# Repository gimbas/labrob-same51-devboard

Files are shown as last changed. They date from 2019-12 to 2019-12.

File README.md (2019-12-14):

# SAME51-DevBoard

small and simple development board for the same51 mcus

## Built With

* eagle cad

## Contributing

Currently not looking for external contributers.

Please read [CONTRIBUTING.md](//) for details on our code of conduct, and the process for submitting pull requests to us.

## Authors

* **Rafael Silva** - *initial work* - [gimbas](https://github.com/gimbas)

See also the list of [contributors](https://github.com/gimbas/labrob-same51-devboard/graphs/contributors) who participated in this project.

## License

This project is licensed under the CC 3.0 License - see the [LICENSE.md](LICENSE.md) file for details

## Acknowledgments

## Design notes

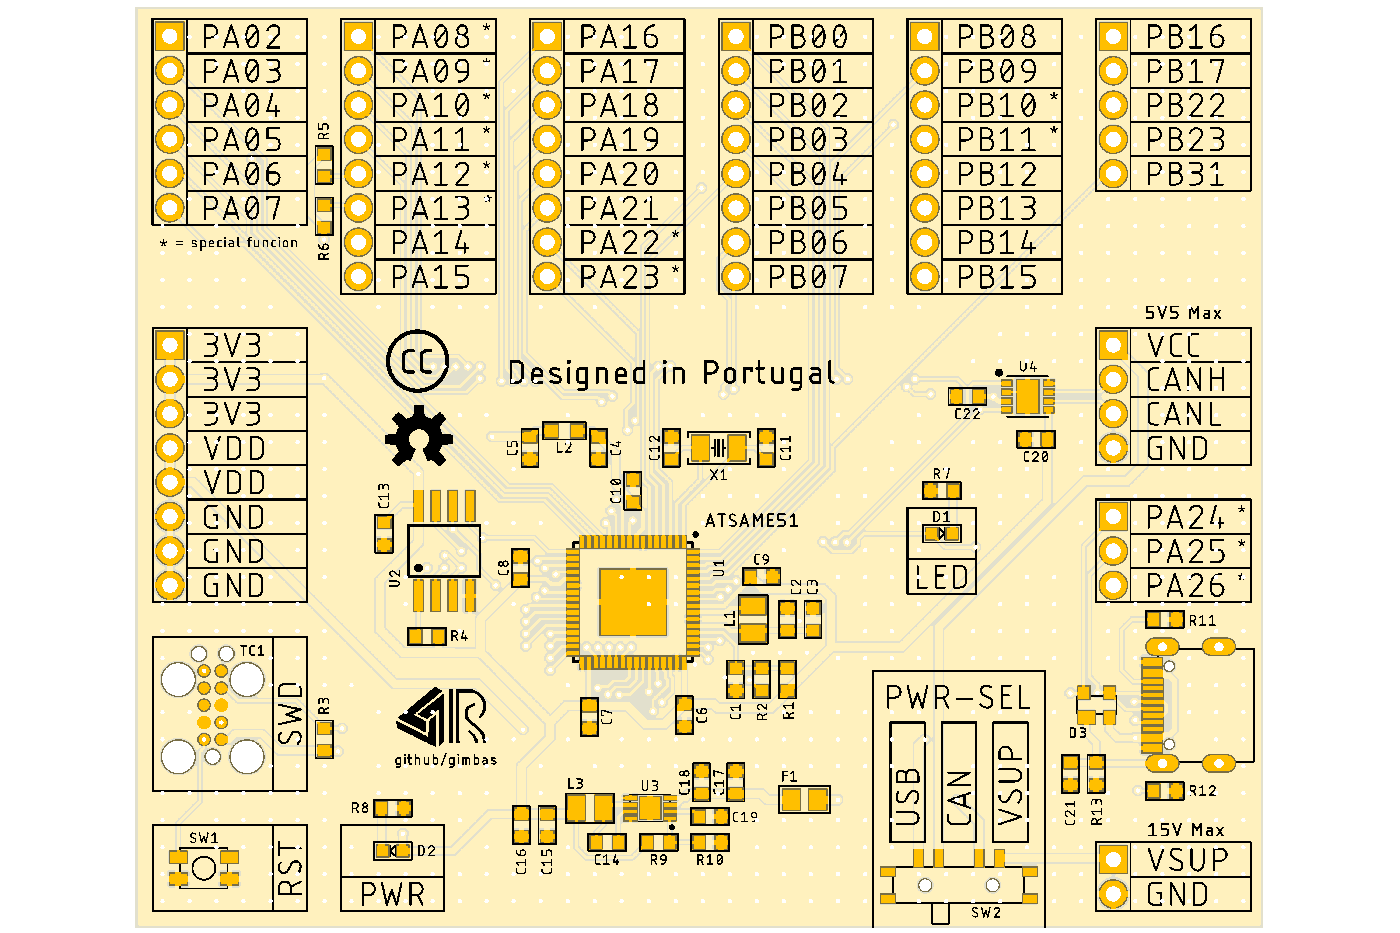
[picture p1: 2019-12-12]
pcb/same51-dev-top-render.png

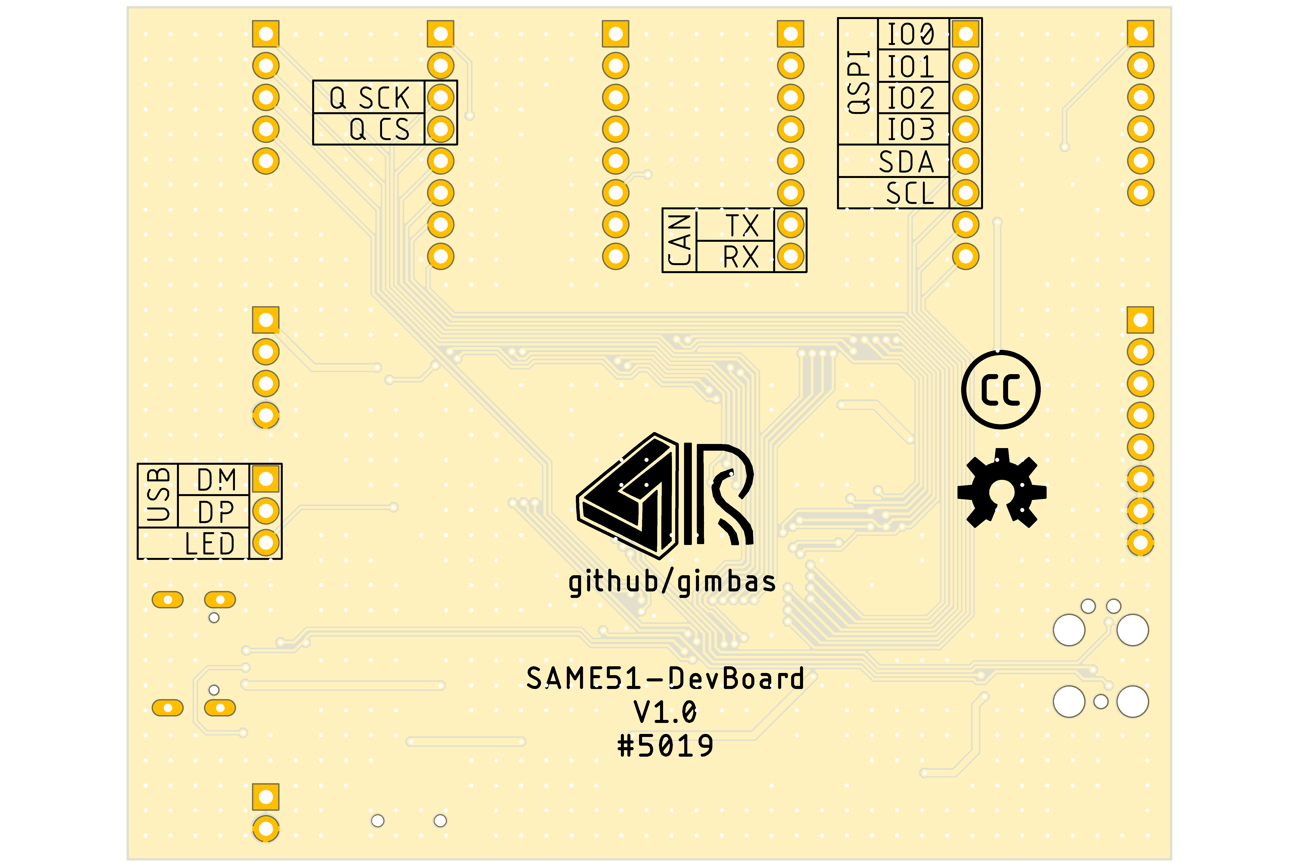
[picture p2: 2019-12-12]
pcb/same51-dev-bot-render.png

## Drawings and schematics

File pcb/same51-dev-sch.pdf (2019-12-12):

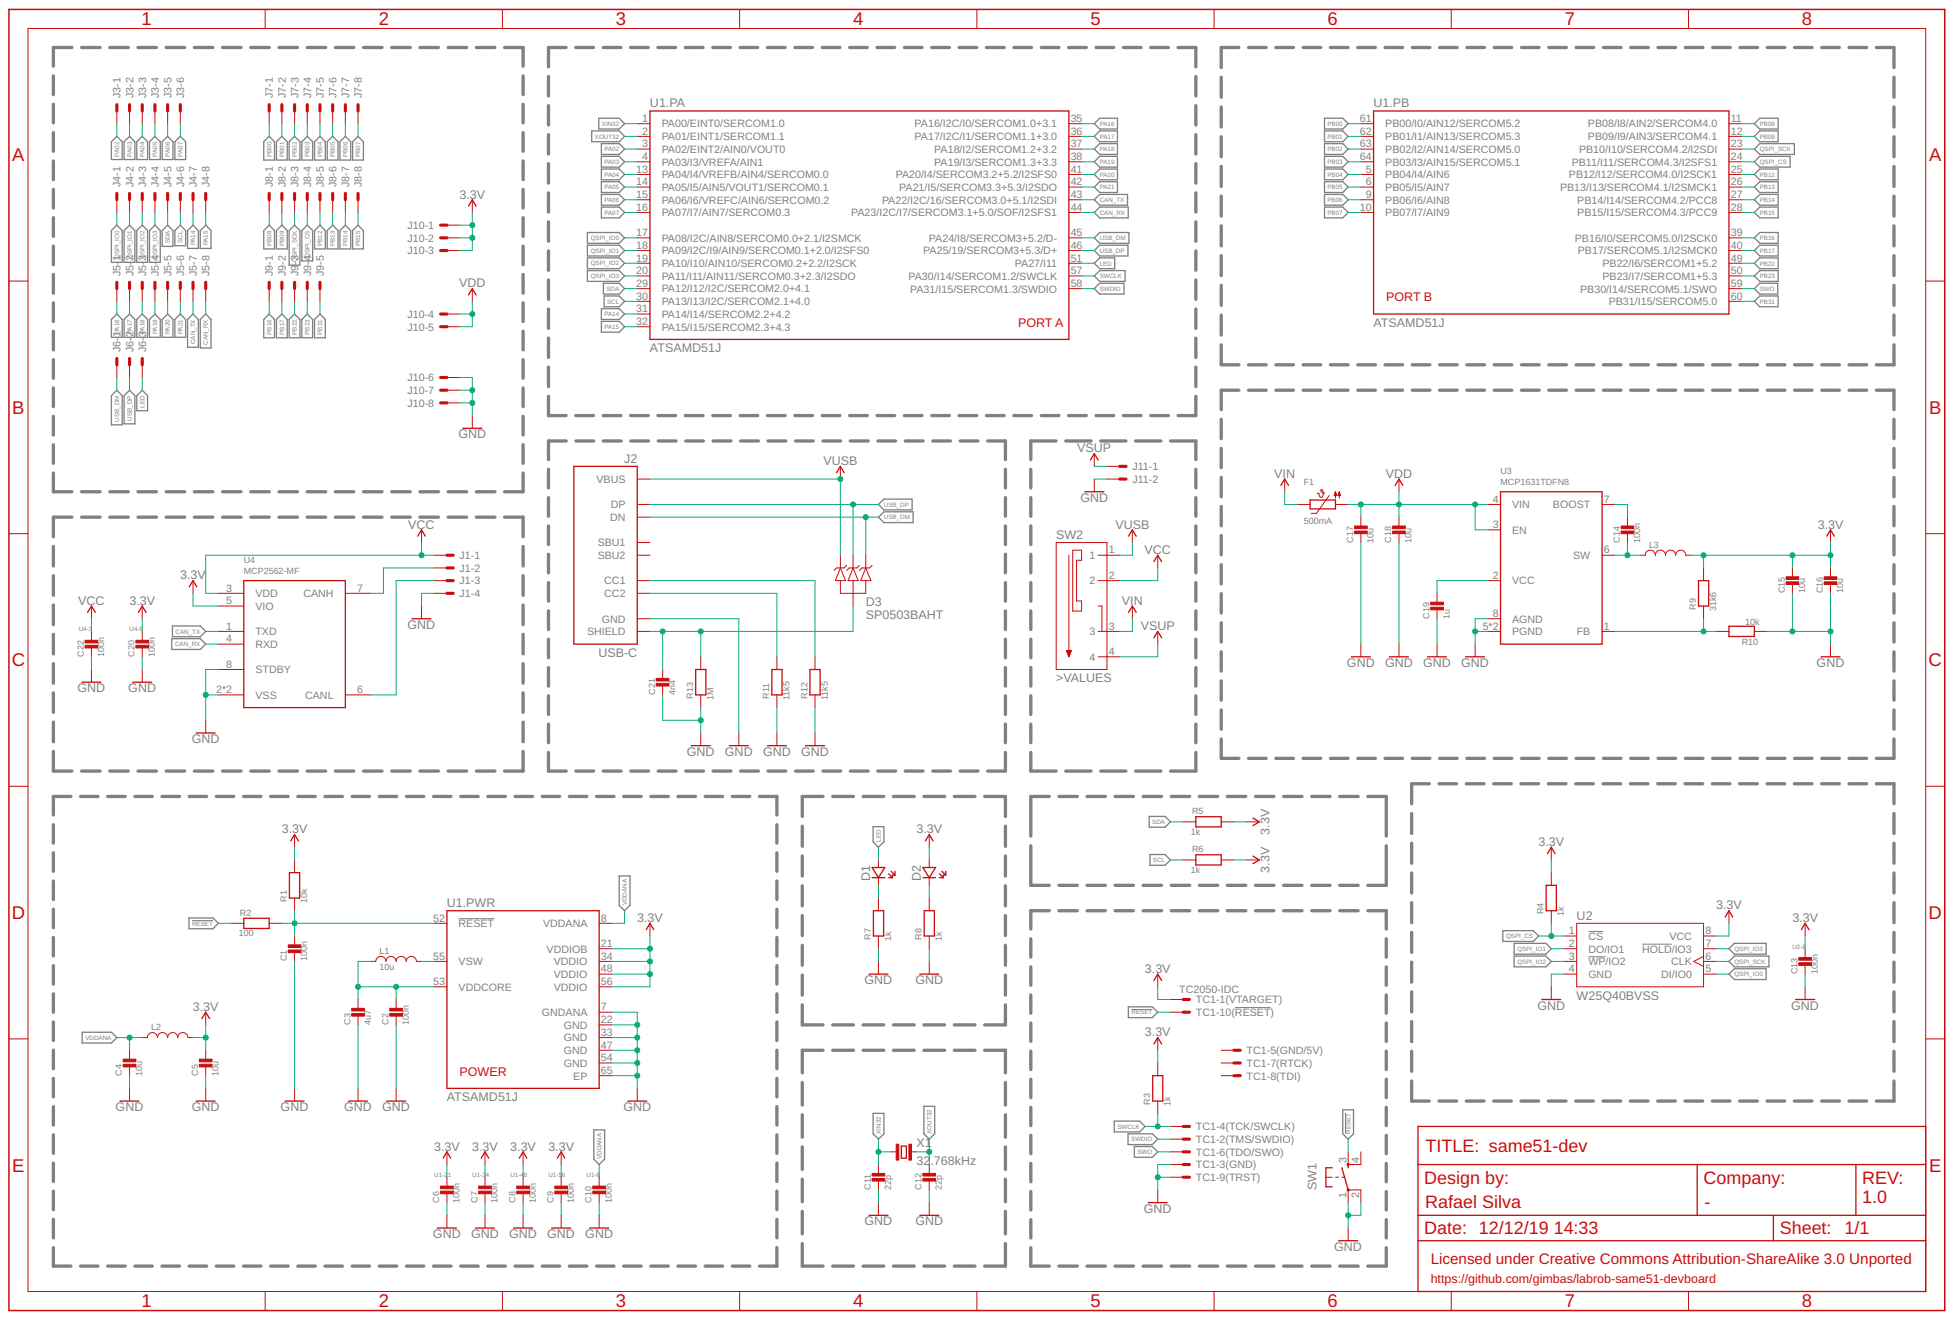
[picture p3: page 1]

n4 GND GND GND GND

TC1-2(TMS/SWDIO) TC1-3(GND) TC1-4(TCK/SWCLK)

Design by: Rafael Silva | Company: - | REV: 1.0

Date: 12/12/19 14:33 | Sheet: 1/1

GND GND GND GND GND

Licensed under Creative Commons Attribution-ShareAlike 3.0 Unported
https://github.com/gimbas/labrob-same51-devboard

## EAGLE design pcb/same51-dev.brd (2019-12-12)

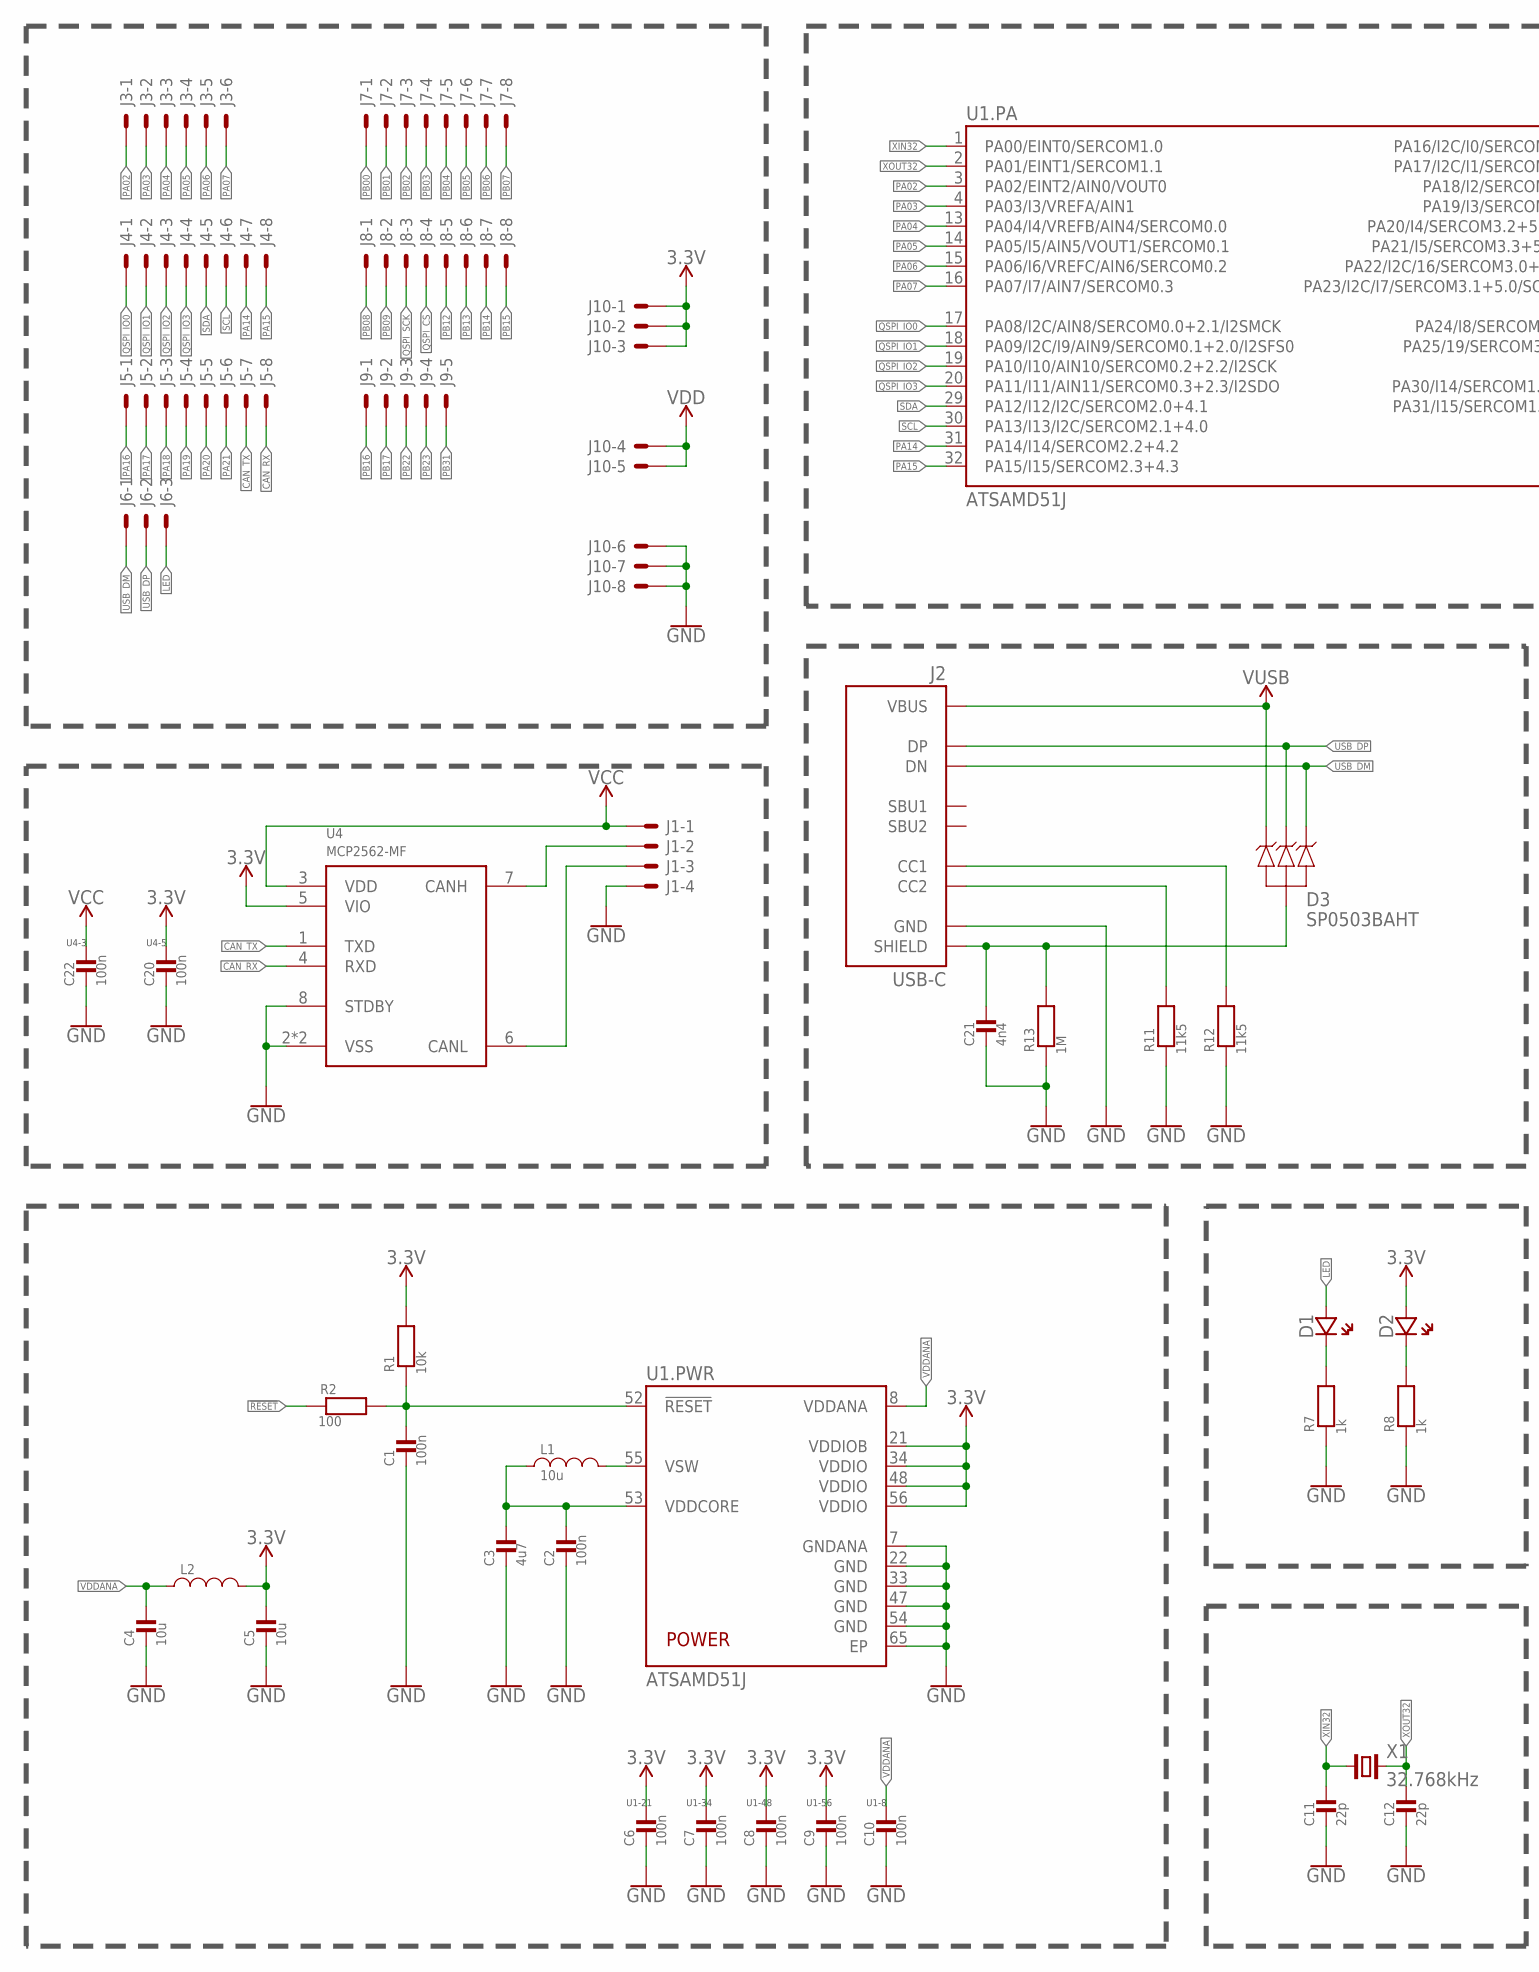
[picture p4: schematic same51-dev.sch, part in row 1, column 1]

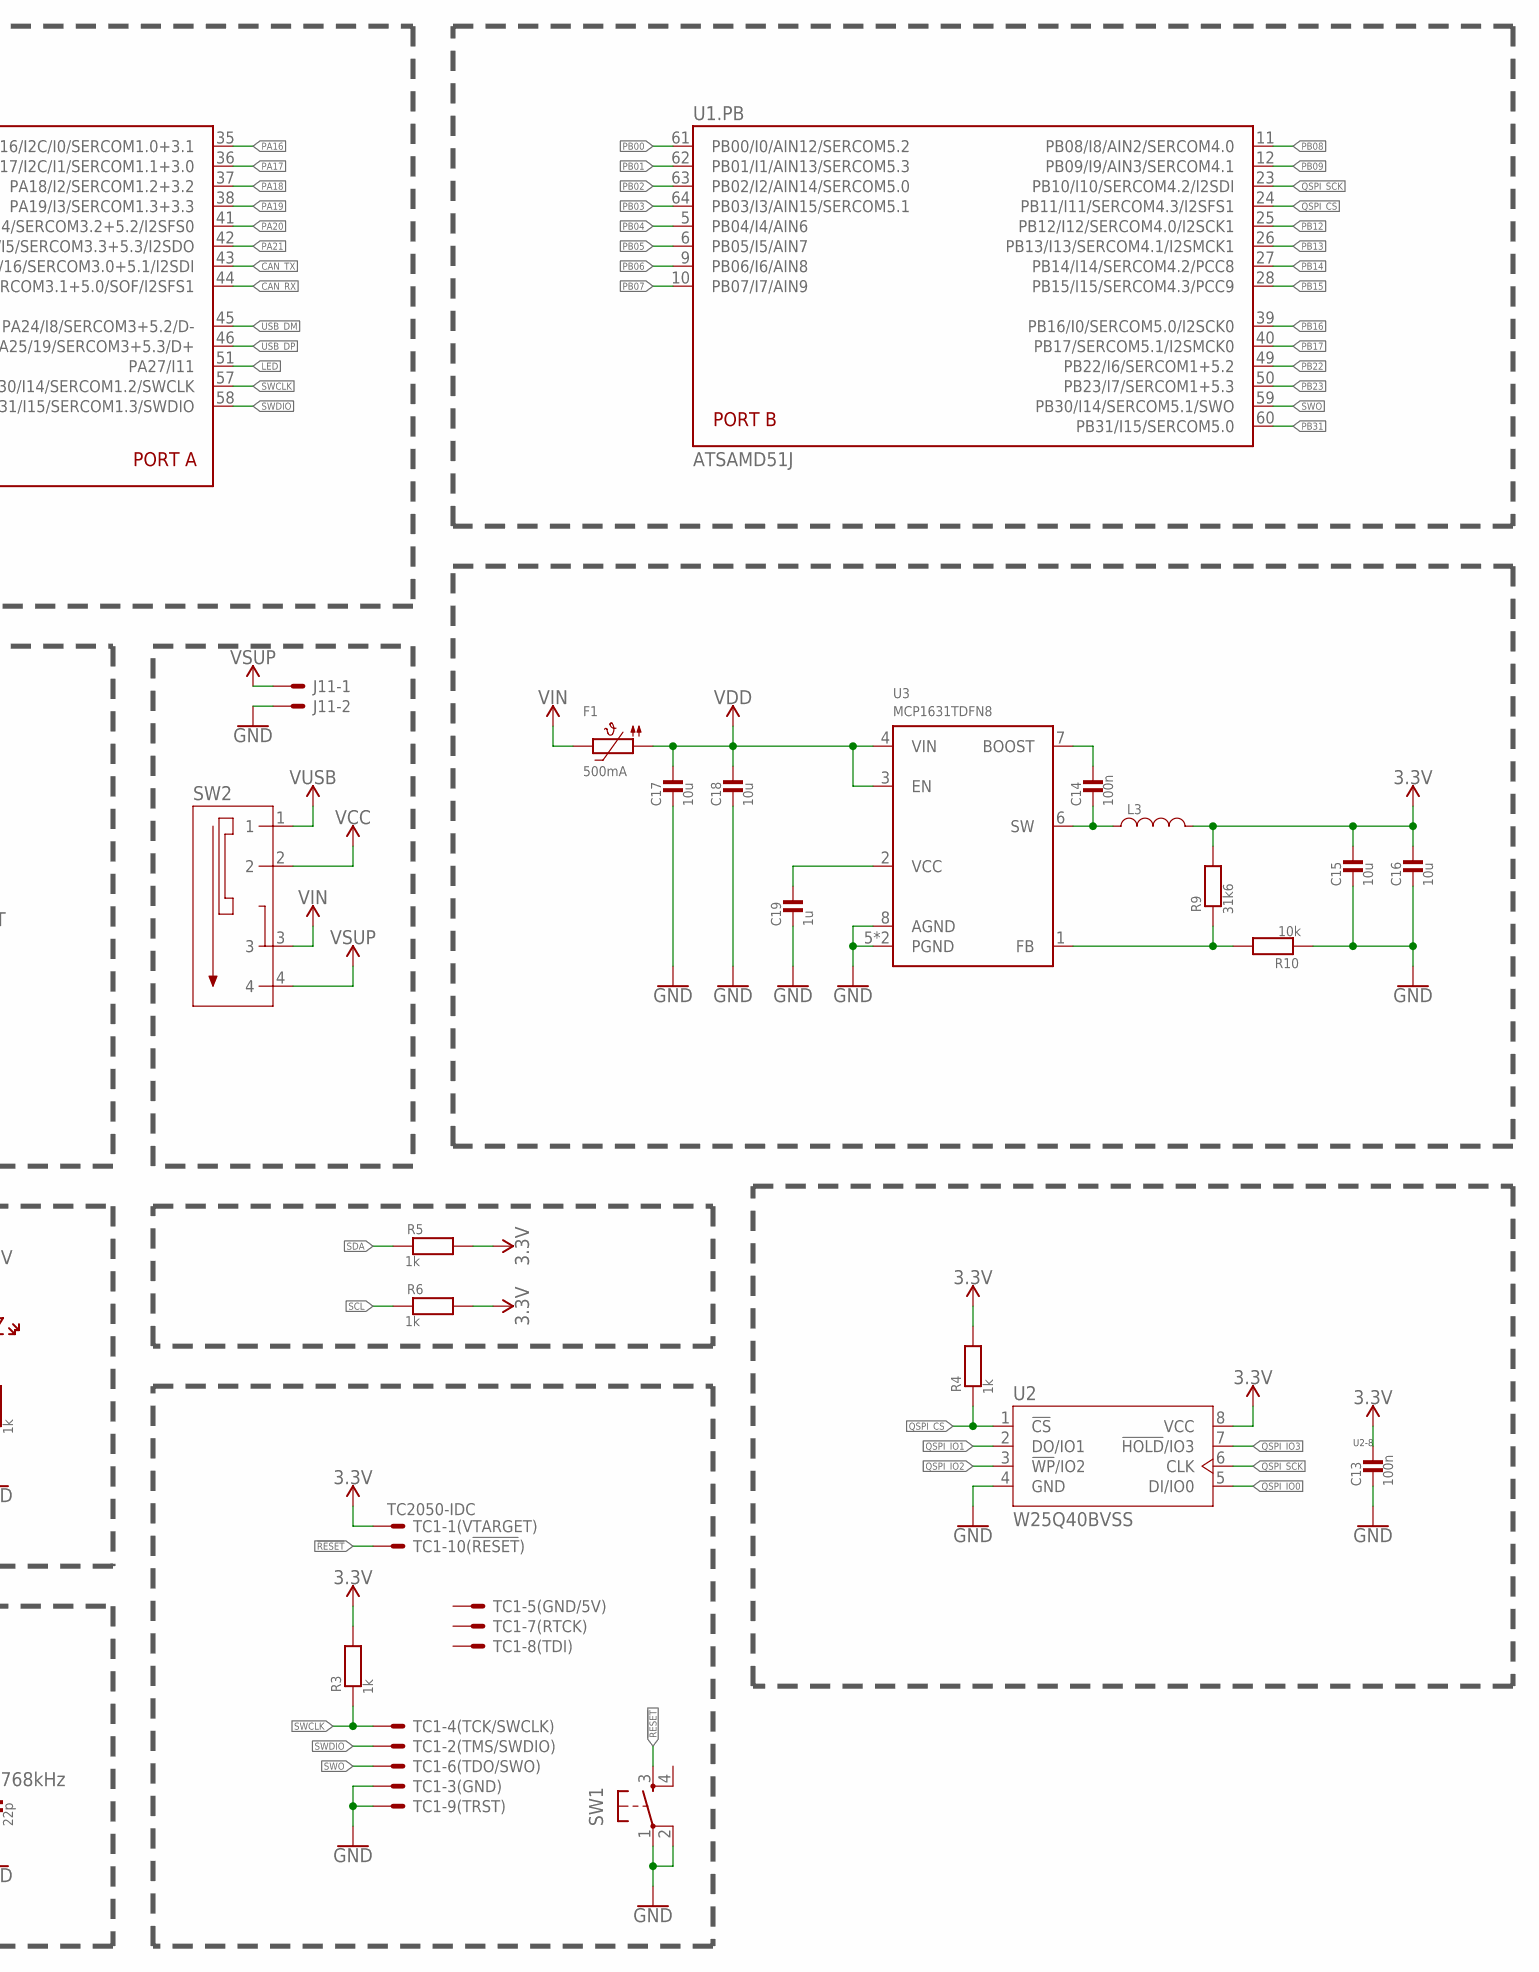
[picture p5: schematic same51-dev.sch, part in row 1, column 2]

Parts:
C1, C2, C6, C7, C8, C9, C10, C13, C14, C20, C22: 100n; 0603_WAVE
C3: 4u7; 0603_WAVE
C4, C5, C15, C16, C17, C18: 10u; 0603_WAVE
C11, C12: 22p; 0603_WAVE
C19: 1u; 0603_WAVE
C21: 4n4; 0603_WAVE
D1, D2: LED0603; CHIPLED_0603
D3: SP0503BAHT; SOT143
F1: 500mA; 0805
J1: 4; 1X4_2.54
J2: USB-C
J3: 6; 1X6_2.54
J4, J5, J7, J8, J10: 8; 1X8_2.54
J6: 3; 1X3_2.54
J9: 5; 1X5_2.54
J11: 2; 2X1_2.54
L1: 10u; _0806
L2: INDUCTOR_NC_0603; _0603
L3: INDUCTOR_NC_0806; _0806
R1, R10: 10k; 0603_WAVE
R2: 100; 0603_WAVE
R3, R4, R5, R6, R7, R8: 1k; 0603_WAVE
R9: 31k6; 0603_WAVE
R11, R12: 11k5; 0603_WAVE
R13: 1M; 0603_WAVE
SW1: PUSH_BUTTON3X4X2; 3X4X2
SW2: MSK-13C01
TC1: TC2050-IDC
U1: ATSAMD51J; VQFN64
U2: W25Q40BVSS; SO08-SS
U3: MCP1631TDFN8; TDFN8
U4: MCP2562-MF; DFN8
X1: 32.768kHz; 2-SMD-3215

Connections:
3.3V: C5.P$1, C6.P$1, C7.P$1, C8.P$1, C9.P$1, C13.P$1, C15.P$1, C16.P$1, C20.P$1, D2.A (AN), J10.1, J10.2, J10.3, L2.2, L3.2, R1.P$2, R3.P$2, R4.P$2, R5.P$2, R6.P$2, R9.P$2, TC1.1, U1.21 (VDDIOB), U1.34 (VDDIO), U1.48 (VDDIO), U1.56 (VDDIO), U2.8 (VCC), U4.5 (VIO)
!RESET: R2.P$1, SW1.3 (4), TC1.10
CAN_RX: J5.8, U1.44 (PA23/I2C/I7/SERCOM3.1+5.0/SOF/I2SFS1), U4.4 (RXD)
CAN_TX: J5.7, U1.43 (PA22/I2C/16/SERCOM3.0+5.1/I2SDI), U4.1 (TXD)
GND: C1.P$2, C2.P$2, C3.P$2, C4.P$2, C5.P$2, C6.P$2, C7.P$2, C8.P$2, C9.P$2, C10.P$2, C11.P$2, C12.P$2, C13.P$2, C15.P$2, C16.P$2, C17.P$2, C18.P$2, C19.P$2, C20.P$2, C21.P$2, C22.P$2, J1.4, J2.A1/B12 (GND), J2.B1/A12 (GND), J10.6, J10.7, J10.8, J11.2, R7.P$1, R8.P$1, R10.P$1, R11.P$1, R12.P$1, R13.P$1, SW1.1, SW1.2, TC1.3, TC1.9, U1.7 (GNDANA), U1.22 (GND), U1.33 (GND), U1.47 (GND), U1.54 (GND), U1.65 (EP), U2.4 (GND), U3.5 (PGND), U3.8 (AGND), U3.9 (PGND), U4.2 (VSS), U4.8 (STDBY), U4.9 (VSS)
LED: D1.A (AN), J6.3, U1.51 (PA27/I11)
unnamed: C1.P$1, R1.P$1, R2.P$2, U1.52 (!RESET)
unnamed: L1.2, U1.55 (VSW)
unnamed: C2.P$1, C3.P$1, L1.1, U1.53 (VDDCORE)
unnamed: C14.P$1, U3.7 (BOOST)
unnamed: C14.P$2, L3.1, U3.6 (SW)
unnamed: R9.P$1, R10.P$2, U3.1 (FB)
unnamed: C19.P$1, U3.2 (VCC)
unnamed: J1.3, U4.6 (CANL)
unnamed: J1.2, U4.7 (CANH)
unnamed: D1.C (CA), R7.P$2
unnamed: C21.P$1, D3.1, J2.SHIELD0 (SHIELD), J2.SHIELD1 (SHIELD), J2.SHIELD2 (SHIELD), J2.SHIELD3 (SHIELD), R13.P$2
unnamed: J2.B5 (CC2), R11.P$2
unnamed: J2.A5 (CC1), R12.P$2
unnamed: D2.C (CA), R8.P$2
PA02: J3.1, U1.3 (PA02/EINT2/AIN0/VOUT0)
PA03: J3.2, U1.4 (PA03/I3/VREFA/AIN1)
PA04: J3.3, U1.13 (PA04/I4/VREFB/AIN4/SERCOM0.0)
PA05: J3.4, U1.14 (PA05/I5/AIN5/VOUT1/SERCOM0.1)
PA06: J3.5, U1.15 (PA06/I6/VREFC/AIN6/SERCOM0.2)
PA07: J3.6, U1.16 (PA07/I7/AIN7/SERCOM0.3)
PA14: J4.7, U1.31 (PA14/I14/SERCOM2.2+4.2)
PA15: J4.8, U1.32 (PA15/I15/SERCOM2.3+4.3)
PA16: J5.1, U1.35 (PA16/I2C/I0/SERCOM1.0+3.1)
PA17: J5.2, U1.36 (PA17/I2C/I1/SERCOM1.1+3.0)
PA18: J5.3, U1.37 (PA18/I2/SERCOM1.2+3.2)
PA19: J5.4, U1.38 (PA19/I3/SERCOM1.3+3.3)
PA20: J5.5, U1.41 (PA20/I4/SERCOM3.2+5.2/I2SFS0)
PA21: J5.6, U1.42 (PA21/I5/SERCOM3.3+5.3/I2SDO)
PB00: J7.1, U1.61 (PB00/I0/AIN12/SERCOM5.2)
PB01: J7.2, U1.62 (PB01/I1/AIN13/SERCOM5.3)
PB02: J7.3, U1.63 (PB02/I2/AIN14/SERCOM5.0)
PB03: J7.4, U1.64 (PB03/I3/AIN15/SERCOM5.1)
PB04: J7.5, U1.5 (PB04/I4/AIN6)
PB05: J7.6, U1.6 (PB05/I5/AIN7)
PB06: J7.7, U1.9 (PB06/I6/AIN8)
PB07: J7.8, U1.10 (PB07/I7/AIN9)
PB08: J8.1, U1.11 (PB08/I8/AIN2/SERCOM4.0)
PB09: J8.2, U1.12 (PB09/I9/AIN3/SERCOM4.1)
PB12: J8.5, U1.25 (PB12/I12/SERCOM4.0/I2SCK1)
PB13: J8.6, U1.26 (PB13/I13/SERCOM4.1/I2SMCK1)
PB14: J8.7, U1.27 (PB14/I14/SERCOM4.2/PCC8)
PB15: J8.8, U1.28 (PB15/I15/SERCOM4.3/PCC9)
PB16: J9.1, U1.39 (PB16/I0/SERCOM5.0/I2SCK0)
PB17: J9.2, U1.40 (PB17/SERCOM5.1/I2SMCK0)
PB22: J9.3, U1.49 (PB22/I6/SERCOM1+5.2)
PB23: J9.4, U1.50 (PB23/I7/SERCOM1+5.3)
PB31: J9.5, U1.60 (PB31/I15/SERCOM5.0)
QSPI_CS: J8.4, R4.P$1, U1.24 (PB11/I11/SERCOM4.3/I2SFS1), U2.1 (!CS!)
QSPI_IO0: J4.1, U1.17 (PA08/I2C/AIN8/SERCOM0.0+2.1/I2SMCK), U2.5 (DI/IO0)
QSPI_IO1: J4.2, U1.18 (PA09/I2C/I9/AIN9/SERCOM0.1+2.0/I2SFS0), U2.2 (DO/IO1)
QSPI_IO2: J4.3, U1.19 (PA10/I10/AIN10/SERCOM0.2+2.2/I2SCK), U2.3 (!WP!/IO2)
QSPI_IO3: J4.4, U1.20 (PA11/I11/AIN11/SERCOM0.3+2.3/I2SDO), U2.7 (!HOLD!/IO3)
QSPI_SCK: J8.3, U1.23 (PB10/I10/SERCOM4.2/I2SDI), U2.6 (CLK)
SCL: J4.6, R6.P$1, U1.30 (PA13/I13/I2C/SERCOM2.1+4.0)
SDA: J4.5, R5.P$1, U1.29 (PA12/I12/I2C/SERCOM2.0+4.1)
SWCLK: R3.P$1, TC1.4, U1.57 (PA30/I14/SERCOM1.2/SWCLK)
SWDIO: TC1.2, U1.58 (PA31/I15/SERCOM1.3/SWDIO)
SWO: TC1.6, U1.59 (PB30/I14/SERCOM5.1/SWO)
USB_DM: D3.4, J2.A7 (DN), J2.B7 (DN), J6.1, U1.45 (PA24/I8/SERCOM3+5.2/D-)
USB_DP: D3.3, J2.A6 (DP), J2.B6 (DP), J6.2, U1.46 (PA25/19/SERCOM3+5.3/D+)
VCC: C22.P$1, J1.1, SW2.2, U4.3 (VDD)
VDD: C17.P$1, C18.P$1, F1.1, J10.4, J10.5, U3.3 (EN), U3.4 (VIN)
VDDANA: C4.P$1, C10.P$1, L2.1, U1.8 (VDDANA)
VIN: F1.2, SW2.3
VSUP: J11.1, SW2.4
VUSB: D3.2, J2.A4/B9 (VBUS), J2.B4/A9 (VBUS), SW2.1
XIN32: C11.P$1, U1.1 (PA00/EINT0/SERCOM1.0), X1.1
XOUT32: C12.P$1, U1.2 (PA01/EINT1/SERCOM1.1), X1.2

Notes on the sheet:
U1-21
U1-34
U1-48
U1-56
U1-8
U2-8
U4-5
U4-3

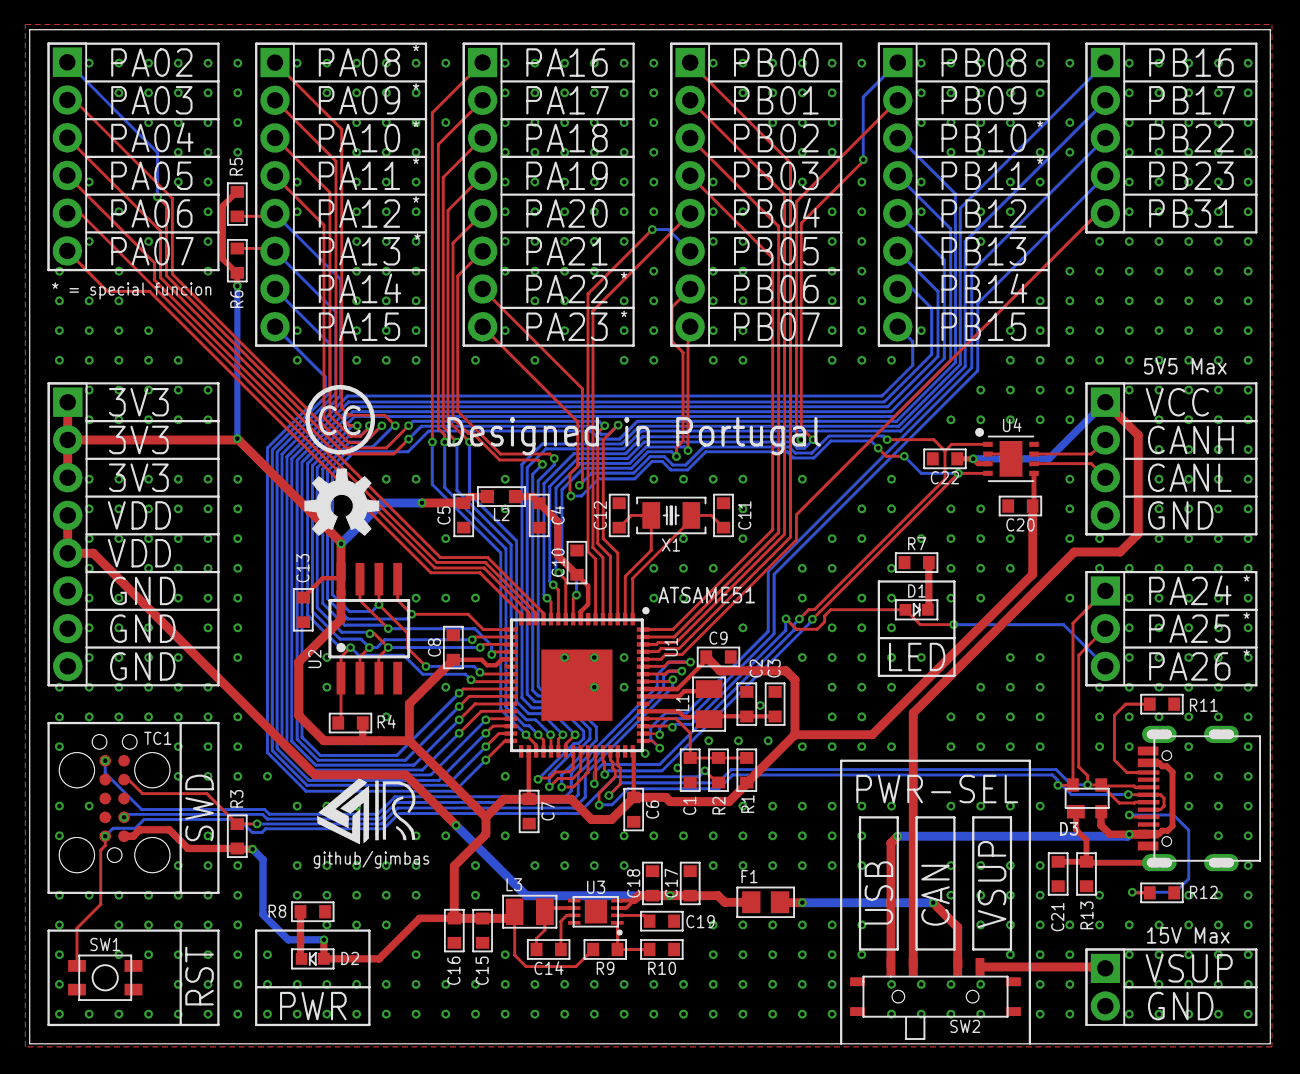
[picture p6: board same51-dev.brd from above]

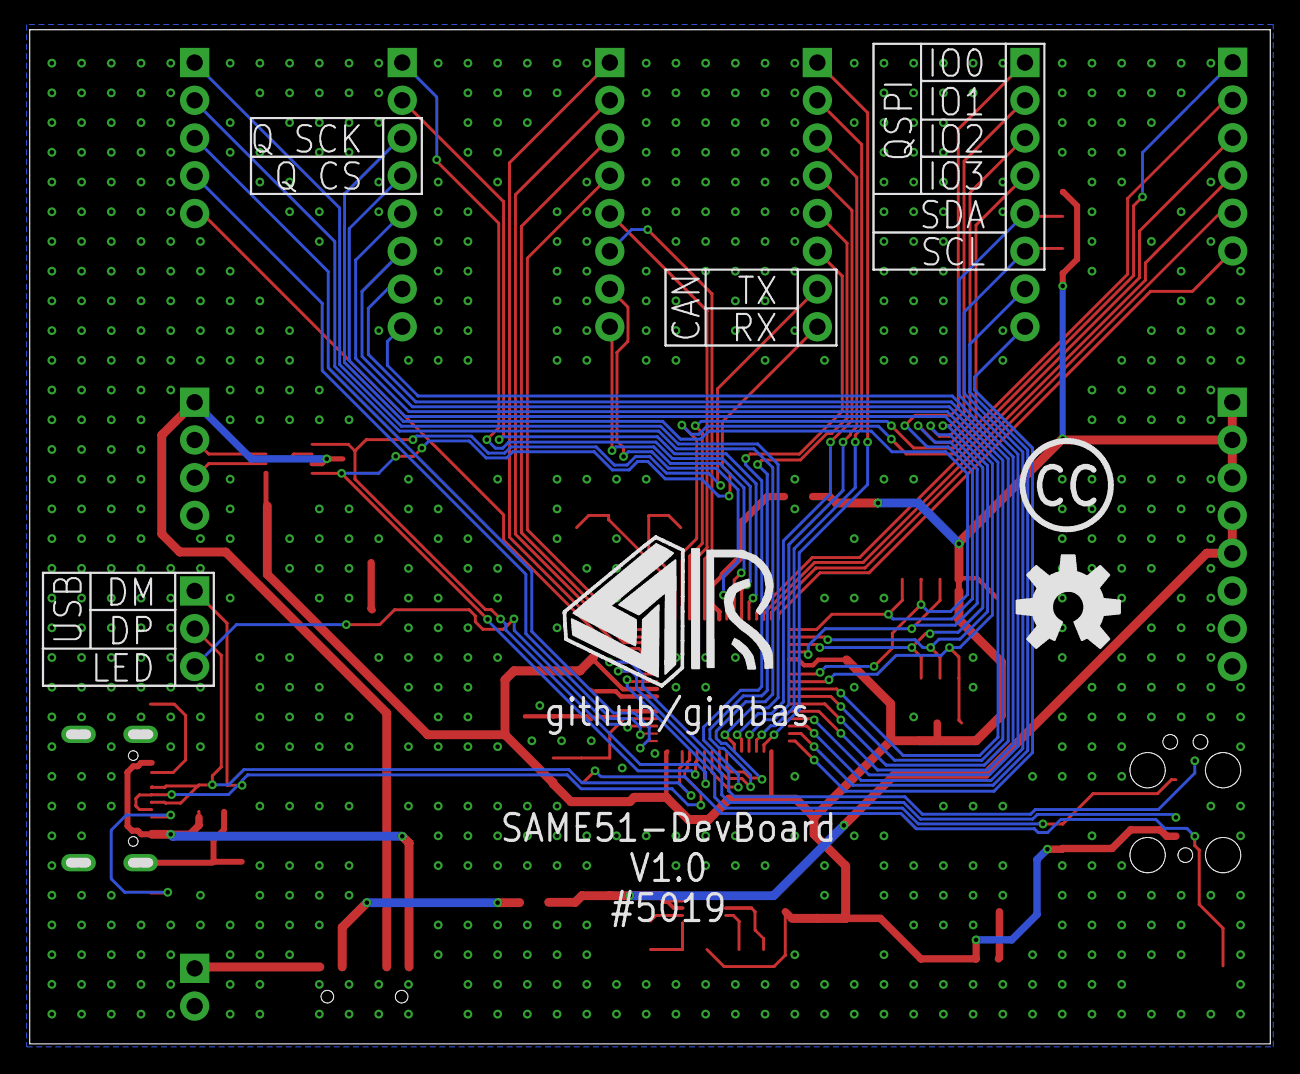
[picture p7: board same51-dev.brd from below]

Board: 2 copper layers, 83.5 x 68.2 mm, 65 parts (2 on the bottom side), 74 nets.

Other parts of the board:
U$1: OSHW-LOGO-L
U$2: RAFAEL_SILVA_10MM_ALT
U$3: RAFAEL_SILVA_5MM_ALT_3
U$4: OSHW-LOGO-M

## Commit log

2019-12-09 sch work
    [same51-dev.sch]
2019-12-09 finished sch, started pcb
    [same51-dev.brd, same51-dev.sch]
2019-12-11 power routing
    [same51-dev.brd, same51-dev.sch]
2019-12-11 finished signal routing
    [same51-dev.brd]
2019-12-12 V1.0 Ready for production
    [same51-dev.brd]

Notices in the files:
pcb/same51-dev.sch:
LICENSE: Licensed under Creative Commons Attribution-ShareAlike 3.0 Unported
